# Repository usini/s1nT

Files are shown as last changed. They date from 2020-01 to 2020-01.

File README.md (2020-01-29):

# s1nT : A 4-Voice Polyphonic Synthetizer for Arduino

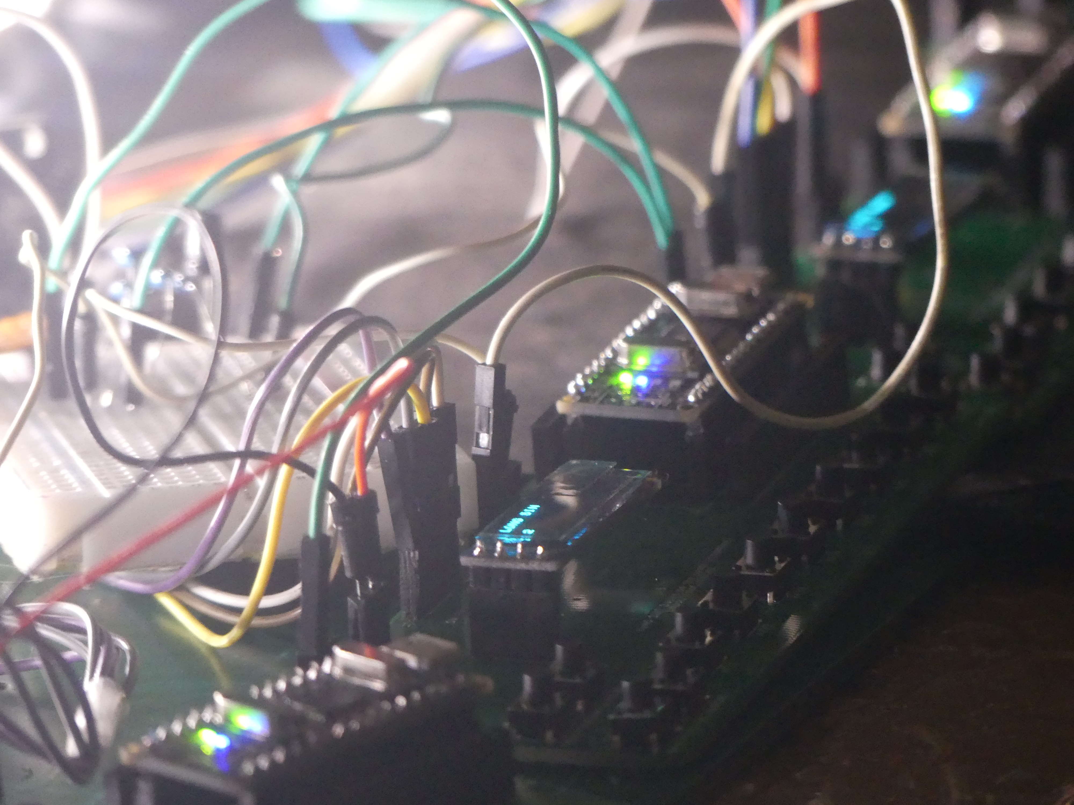
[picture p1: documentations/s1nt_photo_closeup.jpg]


```
          _          ______
         /' \        /\__  _\
    ____/\_, \    ___\/_/\ \/
   /',__\/_/\ \ /' _ `\ \ \ \
  /\__, `\ \ \ \/\ \/\ \ \ \ \
  \/\____/  \ \_\ \_\ \_\ \ \_\
   \/___/    \/_/\/_/\/_/  \/_/
````
Based on the_synth by dzlonline : https://github.com/dzlonline/the_synth

# Libraries Used:
* AceButton : https://github.com/bxparks/AceButton
* the_synth : https://github.com/dzlonline/the_synth

# Schematics
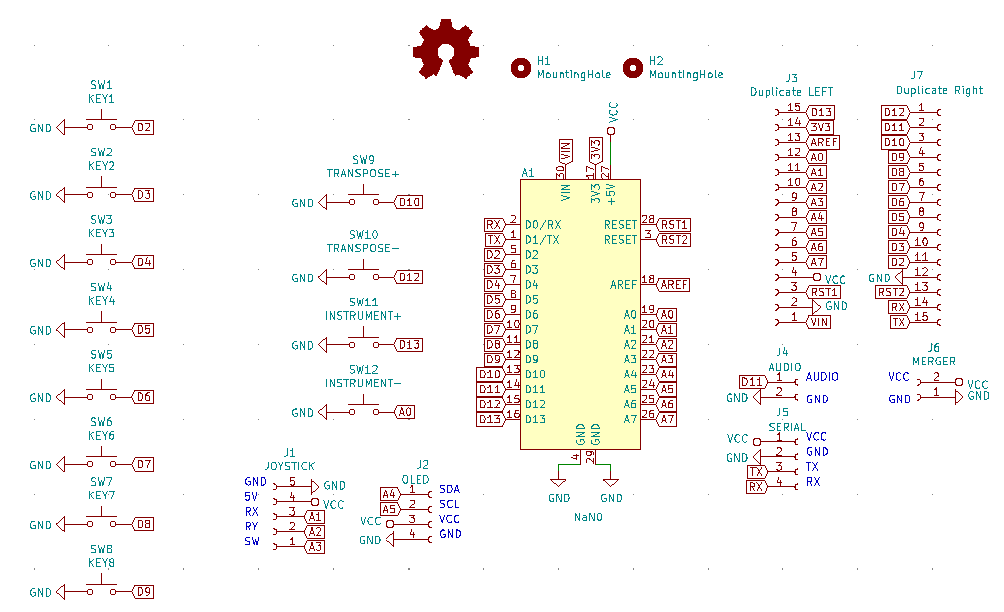
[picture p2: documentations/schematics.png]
Schematics


# Demo
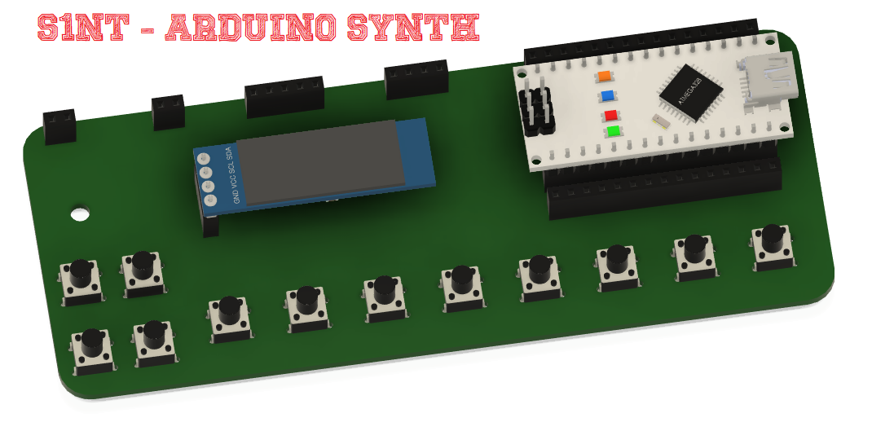
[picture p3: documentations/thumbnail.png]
Thumbnail (https://www.youtube.com/watch?v=24HnNLr4qp4)

https://www.youtube.com/watch?v=24HnNLr4qp4   

Présentation du montage en version Breadboard FR : https://www.youtube.com/watch?v=l1WhdirNEj4

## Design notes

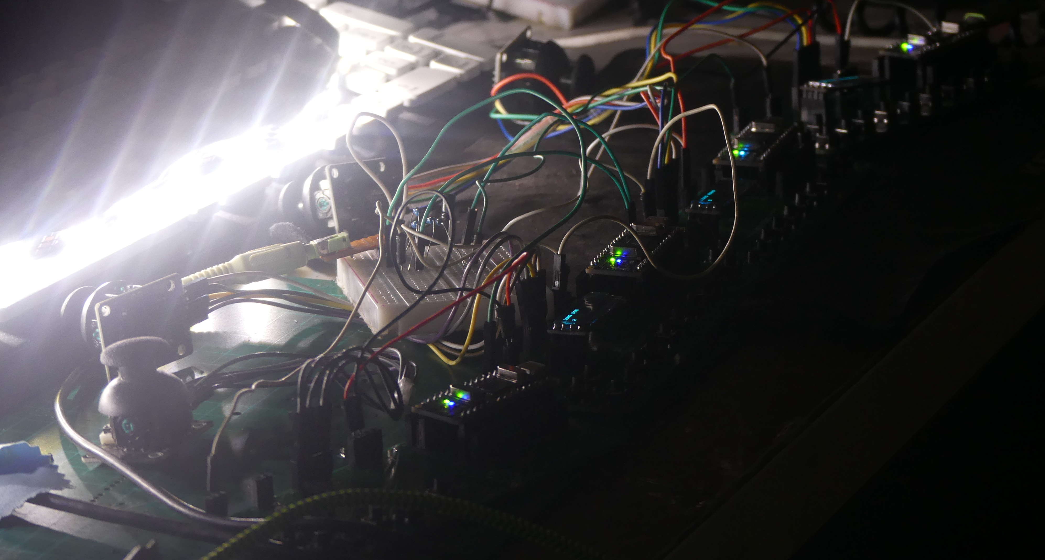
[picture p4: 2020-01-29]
documentations/s1nt_photo.jpg

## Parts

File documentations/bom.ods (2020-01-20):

SinT | Unité Nécessaire | Prix | Unité à l’achat | Unité pour 5 | Unité restantes | Prix pour 5
Boutons 6x6x7mm | 12 | 0,62 € | 20 | 60 | 0 |  | Momentary Tactile 6x6x7 | http://s.click.aliexpress.com/e/olUXpT4y
Connecteurs femelle 5x1 | 1 | 0,66 € | 10 | 5 | 5 | 1,66 € | Single Row Pin Female Header Socket | http://s.click.aliexpress.com/e/CknOkhlQ
Connecteurs femelle 4x1 | 2 | 0,62 € | 10 | 20 | 8 |  | Single Row Pin Female Header Socket | http://s.click.aliexpress.com/e/CknOkhlQ
Connecteurs femelle 2x1 | 2 | 0,32 € | 10 | 10 | 8 |  | Single Row Pin Female Header Socket | http://s.click.aliexpress.com/e/CknOkhlQ
Connecteurs femelle 15x1 | 4 | 0,31 € | 10 | 20 | 6 |  | Single Row Pin Female Header Socket | http://s.click.aliexpress.com/e/CknOkhlQ
Vis M3 | 2 | 6,29 € | 300 | 10 | 298 | 3,05 €
Nano | 1 | 3,20 € | 1 | 5 | 0 | 12,76 € | Arduino Nano | http://s.click.aliexpress.com/e/2uowM4pK
Joystick | 1 | 1,00 € | 1 | 5 | 0 | 3,33 € |  | http://s.click.aliexpress.com/e/DVKoCmBO
Afficheur OLED 128x32 | 1 | 1,55 € | 1 | 5 | 0 | 10,19 € | oled 128x32 I2C | http://s.click.aliexpress.com/e/CBhkgRfE
PCB | 1 | 6,00 € |  |  |  | 6,00 €
Total |  | 20,57 € |  |  |  | 42,74 €
 |  |  |  |  |  | 8,50 €

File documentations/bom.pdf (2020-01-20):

Sheet1

SinT | Unité Nécessaire | Prix | Unité à l’achat Unité pour 5
Boutons 6x6x7mm | 12 | 0,62 € | 20 | 60
Connecteurs femelle 5x1 | 1 | 0,66 € | 10 | 5
Connecteurs femelle 4x1 | 2 | 0,62 € | 10 | 20
Connecteurs femelle 2x1 | 2 | 0,32 € | 10 | 10
Connecteurs femelle 15x1 | 4 | 0,31 € | 10 | 20
Vis M3 | 2 | 6,29 € | 300 | 10
Nano | 1 | 3,20 € | 1 | 5
Joystick | 1 | 1,00 € | 1 | 5
Afficheur OLED 128x32 | 1 | 1,55 € | 1 | 5
PCB | 1 | 6,00 €
Total | | 20,57 €

Unité restantes | Prix pour 5
0 | Momentary Tac (http://s.click.aliexpress.com/e/olUXpT4y)
5 | 1,66 € Single Row Pi
8 | Single Row Pi
8 | Single Row Pi
6 | Single Row Pi
298 | 3,05 €
0 | 12,76 € Arduino Nano
0 | 3,33 €
0 | 10,19 € oled 128x32 I
| 6,00 €
| 42,74 €
| 8,50 €

http://s.click.aliexpress.com/e/olUXpT4yhttp://s.click.aliexpress.com/e/CknOkhlQhttp://s.click.aliexpress.com/e/CknOkhlQhttp://s.click.aliexpress.com/e/CknOkhlQhttp: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

http://s.click.aliexpress.com/e/2uowM4pKhttp://s.click.aliexpress.com/e/DVKoCmBOhttp://s.click.aliexpress.com/e/CBhkgRfEhttp://s.click.aliexpress.com/e/olUXpT4yhttp: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

http://s.click.aliexpress.com/e/2uowM4pKhttp://s.click.aliexpress.com/e/DVKoCmBOhttp://s.click.aliexpress.com/e/CBhkgRfE

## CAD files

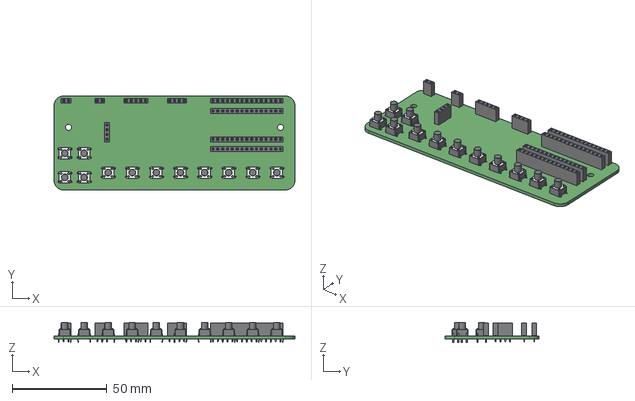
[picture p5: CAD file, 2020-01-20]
kicad/sinT.step
127.0 x 49.5 x 10.8 mm

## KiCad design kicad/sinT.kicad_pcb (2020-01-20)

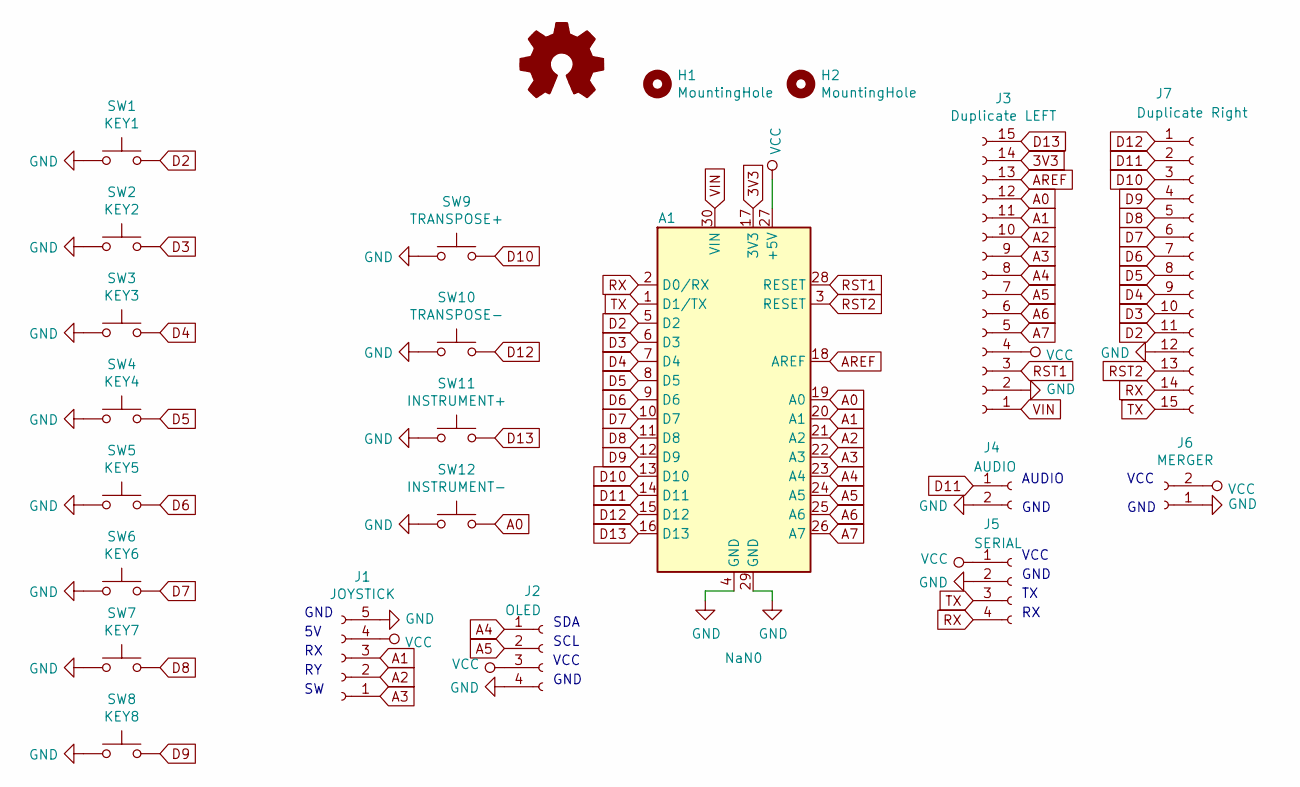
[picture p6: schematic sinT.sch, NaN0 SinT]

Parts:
A1: NaN0; Arduino_Nano
H1, H2: MountingHole; MountingHole_3.2mm_M3
J1: JOYSTICK; PinSocket_1x05_P2.54mm_Vertical
J2: OLED; PinHeader_1x04_P2.54mm_Vertical
J3: Duplicate LEFT; PinSocket_1x15_P2.54mm_Vertical
J4: AUDIO; PinSocket_1x02_P2.54mm_Vertical
J5: SERIAL; PinSocket_1x04_P2.54mm_Vertical
J6: MERGER; PinSocket_1x02_P2.54mm_Vertical
J7: Duplicate Right; PinSocket_1x15_P2.54mm_Vertical
SW1: KEY1; SW_PUSH_6mm_H7.3mm
SW2: KEY2; SW_PUSH_6mm_H7.3mm
SW3: KEY3; SW_PUSH_6mm_H7.3mm
SW4: KEY4; SW_PUSH_6mm_H7.3mm
SW5: KEY5; SW_PUSH_6mm_H7.3mm
SW6: KEY6; SW_PUSH_6mm_H7.3mm
SW7: KEY7; SW_PUSH_6mm_H7.3mm
SW8: KEY8; SW_PUSH_6mm_H7.3mm
SW9: TRANSPOSE+; SW_PUSH_6mm_H7.3mm
SW10: TRANSPOSE-; SW_PUSH_6mm_H7.3mm
SW11: INSTRUMENT+; SW_PUSH_6mm_H7.3mm
SW12: INSTRUMENT-; SW_PUSH_6mm_H7.3mm

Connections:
3V3: A1.17 (3V3), J3.14
A0: A1.19 (A0), J3.12, SW12.2
A1: A1.20 (A1), J1.3, J3.11
A2: A1.21 (A2), J1.2, J3.10
A3: A1.22 (A3), J1.1, J3.9
A4: A1.23 (A4), J2.1, J3.8
A5: A1.24 (A5), J2.2, J3.7
A6: A1.25 (A6), J3.6
A7: A1.26 (A7), J3.5
AREF: A1.18 (AREF), J3.13
D2: A1.5 (D2), J7.11, SW1.2
D3: A1.6 (D3), J7.10, SW2.2
D4: A1.7 (D4), J7.9, SW3.2
D5: A1.8 (D5), J7.8, SW4.2
D6: A1.9 (D6), J7.7, SW5.2
D7: A1.10 (D7), J7.6, SW6.2
D8: A1.11 (D8), J7.5, SW7.2
D9: A1.12 (D9), J7.4, SW8.2
D10: A1.13 (D10), J7.3, SW9.2
D11: A1.14 (D11), J4.1, J7.2
D12: A1.15 (D12), J7.1, SW10.2
D13: A1.16 (D13), J3.15, SW11.2
GND: A1.4 (GND), A1.29 (GND), J1.5, J2.4, J3.2, J4.2, J5.2, J6.1, J7.12, SW1.1, SW2.1, SW3.1, SW4.1, SW5.1, SW6.1, SW7.1, SW8.1, SW9.1, SW10.1, SW11.1, SW12.1
RST1: A1.28 (RESET), J3.3
RST2: A1.3 (RESET), J7.13
RX: A1.2 (D0/RX), J5.4, J7.14
TX: A1.1 (D1/TX), J5.3, J7.15
VCC: A1.27 (+5V), J1.4, J2.3, J3.4, J5.1, J6.2
VIN: A1.30 (VIN), J3.1

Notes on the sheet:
SDA
SCL
VCC
GND
AUDIO

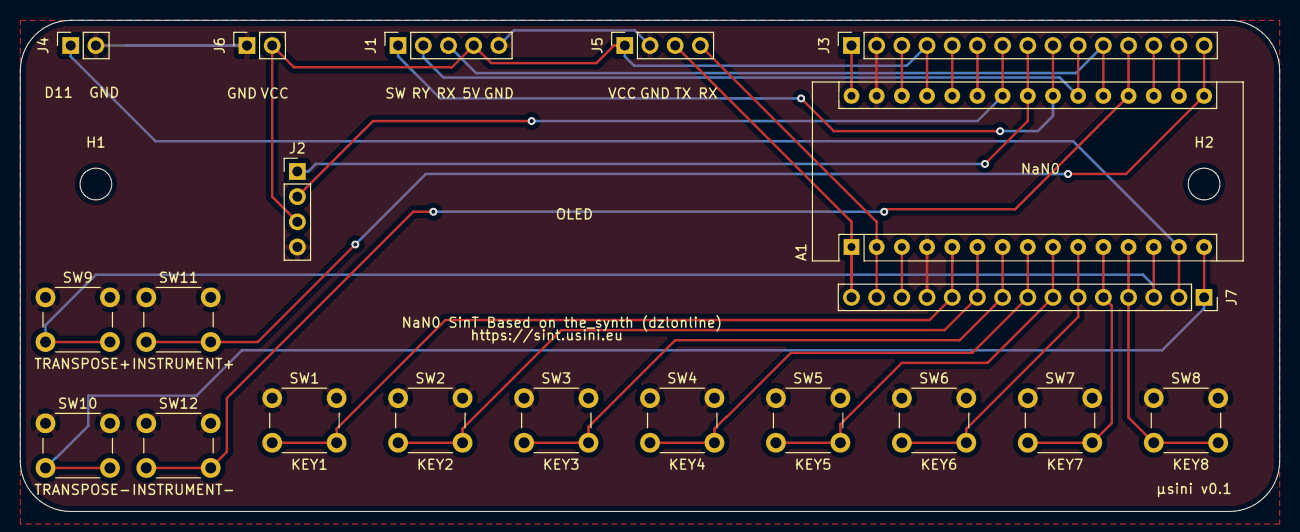
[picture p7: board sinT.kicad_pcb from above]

Board: 2 copper layers, 127.0 x 49.5 mm, 22 parts (0 on the bottom side), 29 nets.

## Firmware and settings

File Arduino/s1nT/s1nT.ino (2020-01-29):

/*         _          ______
         /' \        /\__  _\
    ____/\_, \    ___\/_/\ \/
   /',__\/_/\ \ /' _ `\ \ \ \
  /\__, `\ \ \ \/\ \/\ \ \ \ \
  \/\____/  \ \_\ \_\ \_\ \ \_\
   \/___/    \/_/\/_/\/_/  \/_/

  s1nT : A 4-Voice Polyphonic Synthetizer for Arduino
  Based on the_synth by dzlonline : https://github.com/dzlonline/the_synth
  For more informations go to https://s1nt.usini.eu

  Libraries Used:
  AceButton : https://github.com/bxparks/AceButton
  the_synth : https://github.com/dzlonline/the_synth
  U8x8      : https://github.com/olikraus/u8g2

*/

#include <AceButton.h> // Manage Buttons
#include <synth.h> //The Synth library
#include <Wire.h>
#include <U8x8lib.h> // OLED Library

// Struct for instrument
struct Instrument {
  String name;
  int wave;
  int sustain;
  int release;
  int mod;
};

// Struct of buttons
struct Key {
  const uint8_t pin;
  const uint8_t midiNote;
};

#include "settings.h" // Settings
#include "instruments.h" // Instruments

using namespace ace_button;
synth edgar;

U8X8_SSD1306_128X32_UNIVISION_HW_I2C u8x8(U8X8_PIN_NONE);
String oled_line1 = "";
String oled_line2 = "";

int note_playing = 0;
bool pitch_incourse = false; // Is Pitch active ?

bool mod_incourse = false; // is Mod active ?

int pitch_basic = 0; // Calibration for Joystic Rx
int mod_basic = 0; // Calibration for Joystic Tx
int last_note[4] = {0, 0, 0, 0}; // Last played note
int current_instrument = 0; // Selected instruments

// Mapping wave number to wave name
const String WAVE_NAME[6] = {
  "SIN", // 0
  "TRIANGLE", // 1
  "SQUARE", // 2
  "SAW", // 3
  "RAMP", // 4
  "NOISE" // 5
};

AceButton buttons[NB_BUTTONS];

void setup() {
  Serial.begin(115200);
  u8x8.begin();
  oled_line1 = "usini";
  oled_line2 = "sinT";
  print_screen();
  delay(100);

  init_buttons();    // Init Buttons
  init_pot();        // Init Potentiometer
  edgar.begin();     // Init Synth
  load_instrument(); // Load instrument
}

// Settings buttons as pullup and add a function to handle click event
void init_buttons() {
  pinMode(A3, INPUT_PULLUP);
  for (int i = 0; i < NB_BUTTONS; i++) {
    pinMode(keys[i].pin, INPUT_PULLUP);
    buttons[i].init(keys[i].pin, HIGH, keys[i].midiNote);
  }
  ButtonConfig* buttonConfig = ButtonConfig::getSystemButtonConfig();
  buttonConfig->setEventHandler(handleEvent);
  buttonConfig->setFeature(ButtonConfig::kFeatureClick);
}

// Print on OLED Screen
void print_screen() {
  u8x8.clear();
  u8x8.setFont(u8x8_font_chroma48medium8_r);
  u8x8.drawString(0, 0, oled_line1.c_str());
  u8x8.drawString(0, 2, oled_line2.c_str());
}

// Calibrate Joystick
void init_pot() {
  pitch_basic = analogRead(A1);
  mod_basic = analogRead(A2);
}

// Load Instrument, setup 4-voice and envelope
void load_instrument() {

  /* Turn off all voice */
  for (int i = 0; i < 4; i++) {
    edgar.setLength(i, 0);
  }
  delay(100); // !! WAIT TO AVOID GLITCH SOUND !! \\

  /* Setup Envelope */
  edgar.setupVoice(0, instruments[current_instrument].wave, 127, ENVELOPE0, instruments[current_instrument].sustain, instruments[current_instrument].mod);
  edgar.setupVoice(1, instruments[current_instrument].wave, 127, ENVELOPE1, instruments[current_instrument].sustain, instruments[current_instrument].mod);
  edgar.setupVoice(2, instruments[current_instrument].wave, 127, ENVELOPE2, instruments[current_instrument].sustain, instruments[current_instrument].mod);
  edgar.setupVoice(3, instruments[current_instrument].wave, 127, ENVELOPE3, instruments[current_instrument].sustain, instruments[current_instrument].mod);

  /* Serial Display */
  Serial.print(instruments[current_instrument].name);
  Serial.print(" W:");
  Serial.print(instruments[current_instrument].wave);
  Serial.print(" S:");
  Serial.print(instruments[current_instrument].sustain);
  Serial.print(" R:");
  Serial.print(instruments[current_instrument].release);
  Serial.print(" M:");
  Serial.println(instruments[current_instrument].mod);

  /* OLED Display */
  oled_line1 = instruments[current_instrument].name;
  oled_line2 = transpose;
  print_screen();
}

void loop() {
  for (uint8_t i = 0; i < NB_BUTTONS; i++) {
    buttons[i].check(); // Get Buttons state
  }
  if (pitch_bend) {
    pitch_bend_check(); // Get Joystick Pitch Bend state
  }
  if (mod_bend) {
    mod_bend_check(); // Get Joystick Modulation State
  }
}


// Read Joystick Rx
void pitch_bend_check() {
  int a0_val = analogRead(A1);
  int precision = 4;
  if (!digitalRead(A3)) {
    precision = 8;
  }
  pitch_incourse = true;
  if ((a0_val > pitch_basic + 30) || (a0_val < pitch_basic - 30)) {
    //Serial.print(pitch_basic);
    //Serial.print(" ");
    //Serial.print(a0_val);
    //Serial.print(" ");
    int pitch = (a0_val - pitch_basic) >> precision;
    for (int i = 0; i < 4; i++) {
      Serial.print("P:");
      Serial.print(pitch);
      Serial.print(" N:");
      Serial.println(last_note[i] + pitch);
      edgar.setPitch(i, last_note[i] + pitch);
    }
  } else {
    if (pitch_incourse) {
      pitch_incourse = false;
      for (int i = 0; i < 4; i++) {
        edgar.setPitch(i, last_note[i]);
      }
    }
  }
}

//Read Joystick Ry
void mod_bend_check() {
  int a1_val = analogRead(A2);
  int precision = 3;
  if (!digitalRead(A3)) {
    precision = 6;
  }
  if ((a1_val > mod_basic + 30) || (a1_val < mod_basic - 30)) {
    int mod = a1_val >> precision;
    mod_incourse = true;
    for (int i = 0; i < 4; i++) {
      Serial.print("M:");
      Serial.print(mod);
      Serial.print(" N:");
      Serial.println(mod);
      edgar.setMod(i, mod);
    }
  } else {
    if (mod_incourse) {
      mod_incourse = false;
      for (int i = 0; i < 4; i++) {
        edgar.setMod(i, 64);
      }
    }
  }
}

// Event handle for buttons press
void handleEvent(AceButton* button, uint8_t eventType, uint8_t buttonState) {
  if (eventType == 0) { //Event clicked
    int note = button->getId();
    if (note < 250) { // If note is not a function note
      edgar.setLength(note_playing, instruments[current_instrument].sustain);
      note = note + (8 * transpose);
      edgar.mTrigger(note_playing, note);
      Serial.print(instruments[current_instrument].name);
      Serial.print(" NOTE ON:");
      Serial.println(note);
      last_note[note_playing] = note;
      note_playing++;
      if (note_playing == 4) {
        note_playing = 0;
      }
    } else {
      if (note == 250) { // Transpose button -
        if (transpose > 0) {
          transpose--;
          Serial.println("TRANPOSE -");
          oled_line2 = transpose;
          print_screen();
        }
      }
      if (note == 251) { // Transpose button +
        if (transpose <= 12) {
          Serial.println("TRANPOSE +");
          transpose++;
          oled_line2 = transpose;
          print_screen();
        }
      }
      if (note == 252) { // Instrument button +
        Serial.println("INSTRUMENT +");
        if (current_instrument < NB_INSTRUMENTS - 1) {
          current_instrument++;
          load_instrument();
        }
      }
      if (note == 253) { // Instrument button -
        Serial.println("INSTRUMENT -");
        if (current_instrument > 0) {
          current_instrument--;
          load_instrument();
        }
      }
    }
  }
  if (eventType == 1) { //Event Release
    int note = button->getId();
    if (note < 250) {
      note = button->getId() + (8 * transpose);
      //Serial.print("NOTE:");
      //Serial.print(note);
      for (int i = 0; i < 4; i++) {
        //Serial.print(" I:");
        //Serial.print(last_note[i]);
        if (last_note[i] == note) { // Release notes ( Warning: not mapped correctly)
          Serial.print(instruments[current_instrument].name);
          Serial.print(" NOTE OFF:");
          Serial.println(note);
          edgar.setLength(i, instruments[current_instrument].release);
        }
      }
    }
  }
}

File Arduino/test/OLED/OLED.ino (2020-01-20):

#include <Wire.h> //I2C
#include <U8g2lib.h>
String oled_line1;
String oled_line2;
U8G2_SSD1306_128X32_UNIVISION_F_HW_I2C u8g2(U8G2_R0, /* reset=*/ U8X8_PIN_NONE);

void setup() {
  // put your setup code here, to run once:
  u8g2.begin();
  oled_line1 = "TEST";
  oled_line2 = "TEST2";
  printScreen();
}

void printScreen() {
  //https://github.com/olikraus/u8g2/wiki/fntlist8x8
  u8g2.setFont(u8g2_font_7x14_mr);
  u8g2.firstPage();
  do {
    u8g2.setCursor(0, 14);
    u8g2.println(oled_line1);  // write something to the internal memory
    u8g2.setCursor(0, 30);
    u8g2.println(oled_line2);  // write something to the internal memory
  }
  while ( u8g2.nextPage() );
}

void loop() {
  // put your main code here, to run repeatedly:

}

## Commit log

2020-01-20 add thumbnail / schematics
2020-01-21 Disable pitch/modulation by default
2020-01-29 Wrong pins / add photos
    [s1nT.ino]
